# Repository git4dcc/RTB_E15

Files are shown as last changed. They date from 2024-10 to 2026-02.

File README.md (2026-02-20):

# RTB_E15




This E15 module implements a 12 channel WS2811 emulator with compatible bus timing to drive multiplex (charlieplexing) LEDs. The E15 may be cascaded with regular WS28xx chips. The number of LEDs attached is automatically detected (0-12). The LED voltage is fixed to 5V.  The intended use is to drive Multiplex Signals on Model Railway layouts via the WS28xx bus.

_Note: The E15 is nearly identical to the [RTB_E13](/../../../../git4dcc/RTB_E13), but only allows fixed LED voltage._

<details>
<summary>See also</summary>

- [RTB_E10](/../../../../git4dcc/RTB_E10)
- [RTB_E13](/../../../../git4dcc/RTB_E13)

</details>

<details>
<summary>User Guides</summary>

- [User Guide - DE](https://rtb4dcc.de/ws2811_guide_de/)
- User Guide - EN

</details>

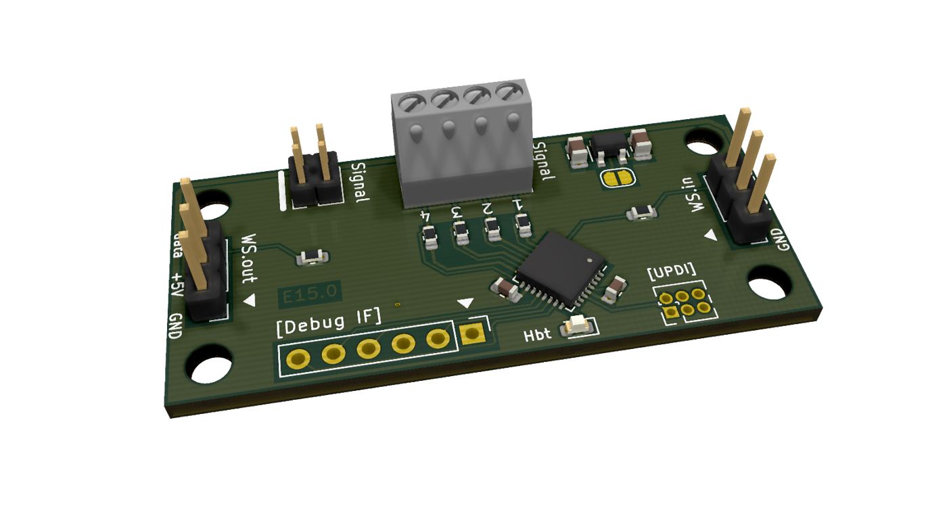
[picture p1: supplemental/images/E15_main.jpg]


The decoder has the following features,
- **Protocol**
  - WS2811 compatible timing
- **LED ports**
  - 0..12 LEDs (auto detecting)
  - Charlieplexing (Multiplexing) output
  - 256 step PWM (300Hz)
  - LED voltage fixed to 5V (see also [RTB_E13](https://github.com/git4dcc/RTB_E13))
  - gamma correction (optional)
- firmware update via V24 debug interface

# Hardware
My current PCB layout uses SMD footprints with 0.5mm pitch and 0603 parts. Reflow soldering is my recommendation, but with some experience handsoldering is also possible.

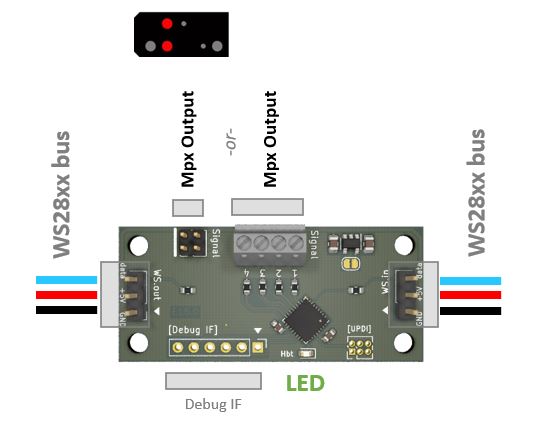
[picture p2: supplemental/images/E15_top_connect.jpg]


## PCB
- 2-layer PCB, FR4, 1.6mm
- CPU: AVR64DA32
- BUS: WS28xx
- LED: Charlieplexing

## Kicad
[Schematic](doc/E15_schematic.pdf) | [Layout](doc/E15_layout.pdf) | [BOM](doc/E15_BOM.pdf) | [Gerber](gerber)

<details>
<summary>Dependency</summary>
<br>

:yellow_circle: Requires my Kicad project library [RTB_SamacSys](/../../../../git4dcc/RTB_SamacSys) in the same directory tree.

</details>

## Firmware
Filename structure: { **pcb** }{ **code** }{ **version** }.hex

Example: **E15F0001**.hex

| | Description |
| --- | --- |
| **pcb** | Name of matching hardware (**E15**) |
| **code** | Type of code contained (**R**=rom, **B**=bootloader, **F**=flash, **U**=bld update, **P**=UPDI factory code) |
| **version** | Release version (**####**) |

## UPDI
The fuse settings as well as the P-code (E15Pxxxx.hex) has to be installed by using UPDI.<br>

<details>
<summary>Details</summary>

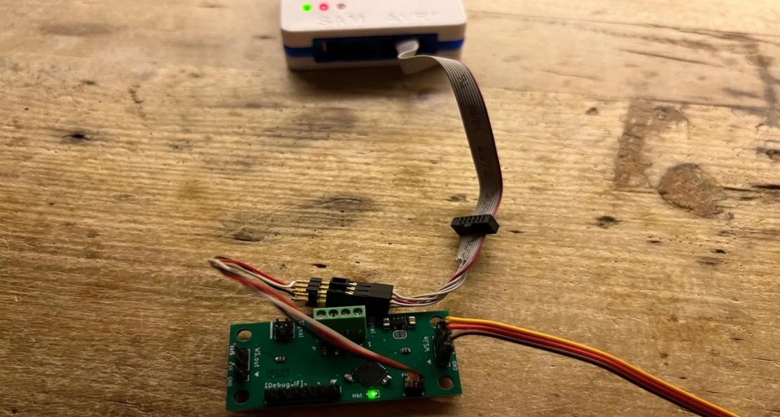
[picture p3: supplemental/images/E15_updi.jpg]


| Fuse Setting | P-code Install |
| --- | --- |
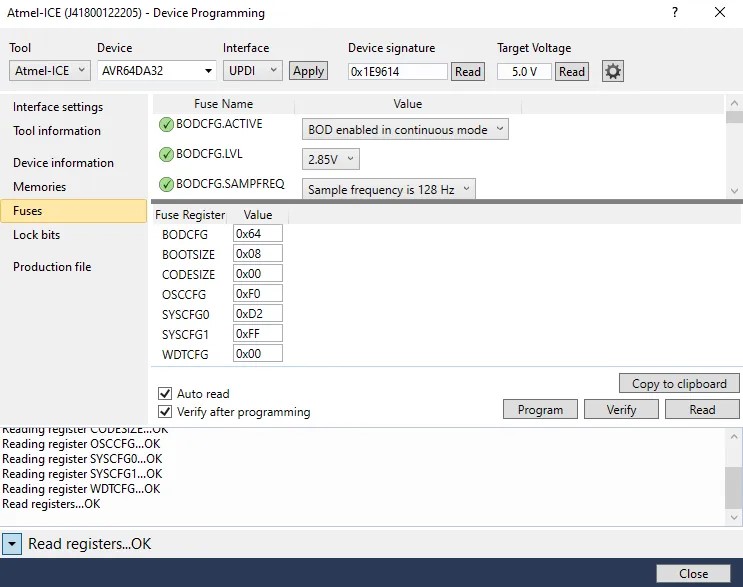
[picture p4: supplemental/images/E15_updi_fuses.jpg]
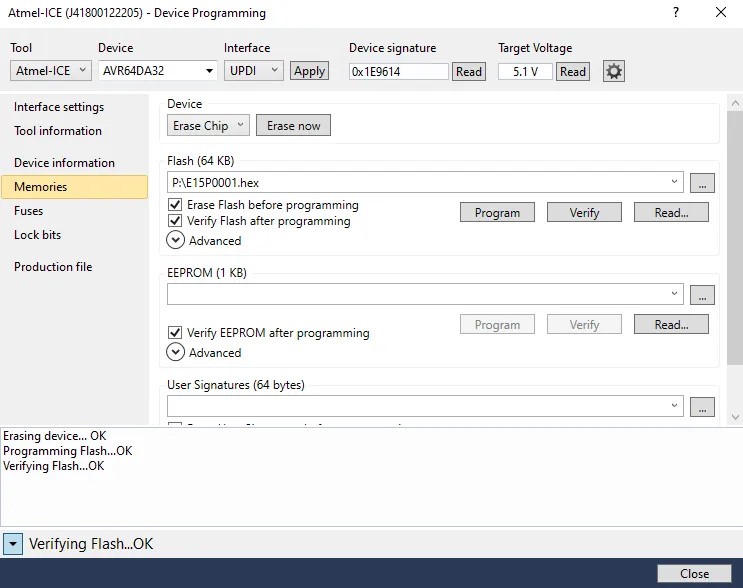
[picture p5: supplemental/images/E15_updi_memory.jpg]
|||

</details>

## Debug Interface
Subsequent code updates can be done via the built-in serial debug interface.<br>

<details>
<summary>Details</summary>

- connect the serial cable **(1Mb, 8N1, RTS/CTS)**
- press 'break' within the VT100 terminal to bump the module to console prompt
- upload the firmware file (E15Fxxxx.hex)
- for more details, refer to the 'User Guide'

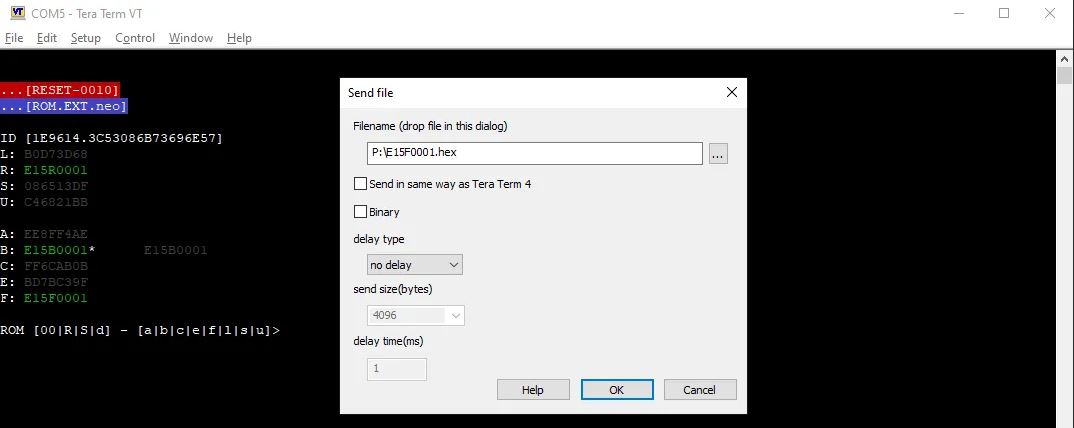
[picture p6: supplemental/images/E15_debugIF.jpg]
  

</details>

# Software
The LED intensity values for the individual LEDs need to be transmitted over the bus, with N being the number of configured LEDs.

```
Byte order:     {led_0} ... {led_N}
```

# Images
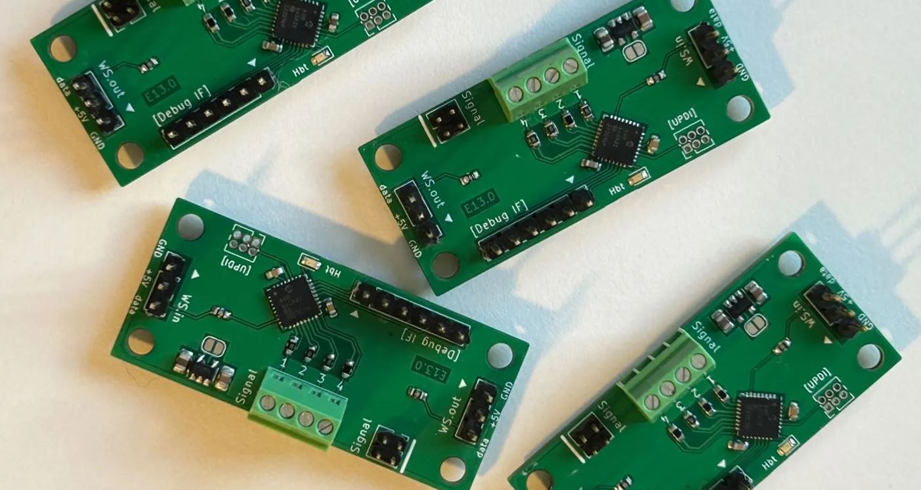
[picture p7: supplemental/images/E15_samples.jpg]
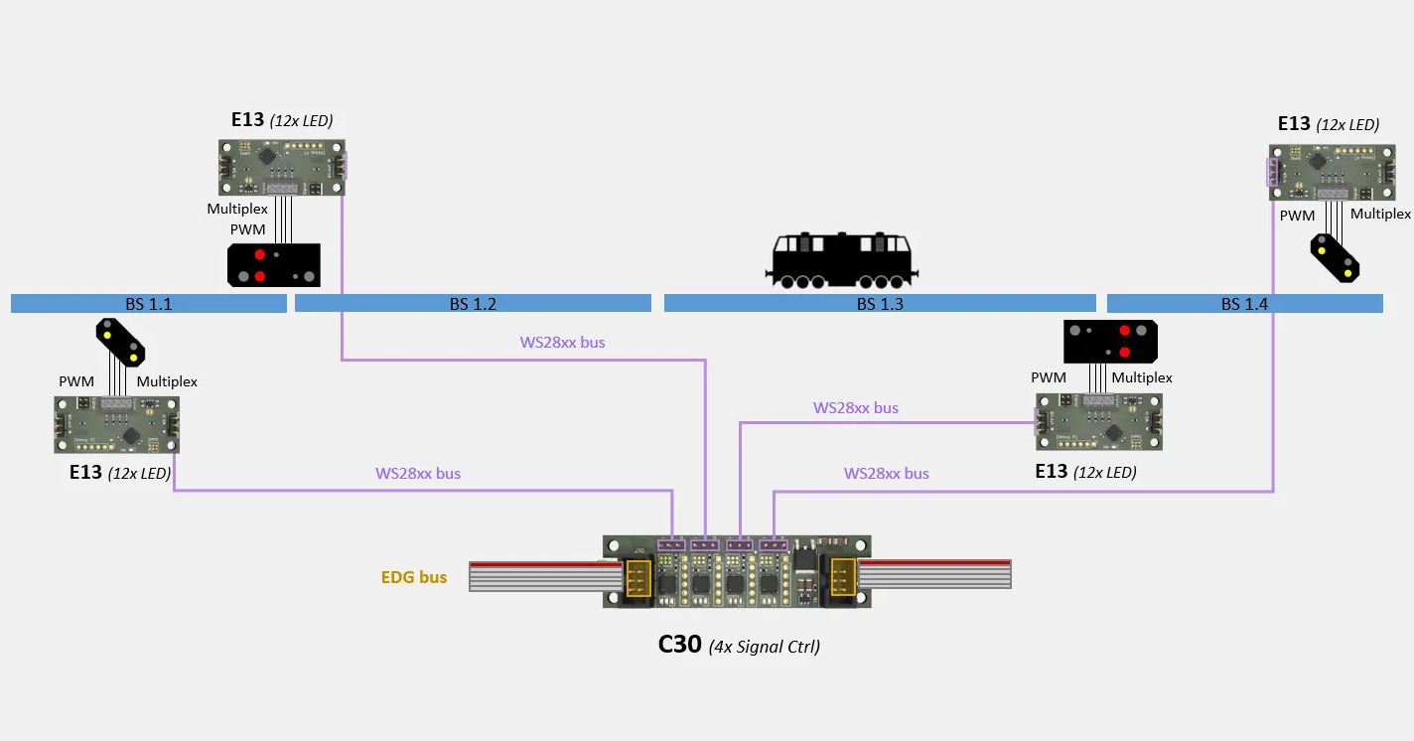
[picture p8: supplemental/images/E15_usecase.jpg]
 

This project is intended for hobby use only and is distributed in accordance with the Apache License 2.0 agreement.

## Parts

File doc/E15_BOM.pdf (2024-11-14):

Item# | Designator | Qty | Manufacturer | Mfg Part# | Description / Value | Package/Footprint | Type | Notes
1 | C2,C3 | 2 | Murata Electronics | GCM188R71C104KA37J | Multilayer Ceramic Capacitors MLCC 0.1 uF 16 VDC 10% X7R | 0603 | SMD | any compatible part will do as well
2 | D2 | 1 | ROHM Semiconductor | SMLD12EN1WT86 | Standard LEDs - SMD Grn 140mcd | 0603 | SMD | any compatible part will do as well
3 | R17,R16,R15,R14 4 | YAGEO | RC0603FR-07120RL | Thick Film Resistors 120 Ohms 100mW 1% | 0603 | SMD | any compatible part will do as well
4 | R19,R18 | 2 | YAGEO | AC0603FR-07160RL | Thick Film Resistors 160 Ohms 100mW 1% | 0603 | SMD | any compatible part will do as well
5 | R20 | 1 | YAGEO | RC0603JR-103K3L | Thick Film Resistors 3.3 kOhms 100-200mW 5% | 0603 | SMD | any compatible part will do as well
6 | C4,C1 | 2 | Murata Electronics | GRM21BZ7YA475ME15L | Multilayer Ceramic Capacitors MLCC 4.7 uF 35 VDC 20% X7R | 0805 | SMD | any compatible part will do as well
7 | U2 | 1 | Microchip Technology | MIC5205-5.0YM5-TR | LDO Voltage Regulators 5V 150mA | SOT-23-5 | SMD | any compatible part will do as well
8 | U1 | 1 | Microchip Technology | AVR64DA32-I/RXB | 8-bit Microcontrollers - MCU 64 KB 32-pin | QFN-32 5x5mm P0.5mm | SMD

Item# | Designator | Qty | Manufacturer | Mfg Part# | Description / Value | Package/Footprint | Type | Notes 1 | D2 | 1 | Vishay | SSA33L-E3/61T | Schottky Diodes & Rectifiers 3.0 Amp 30 Volt | SMA | SMD | any compatible part will do as well

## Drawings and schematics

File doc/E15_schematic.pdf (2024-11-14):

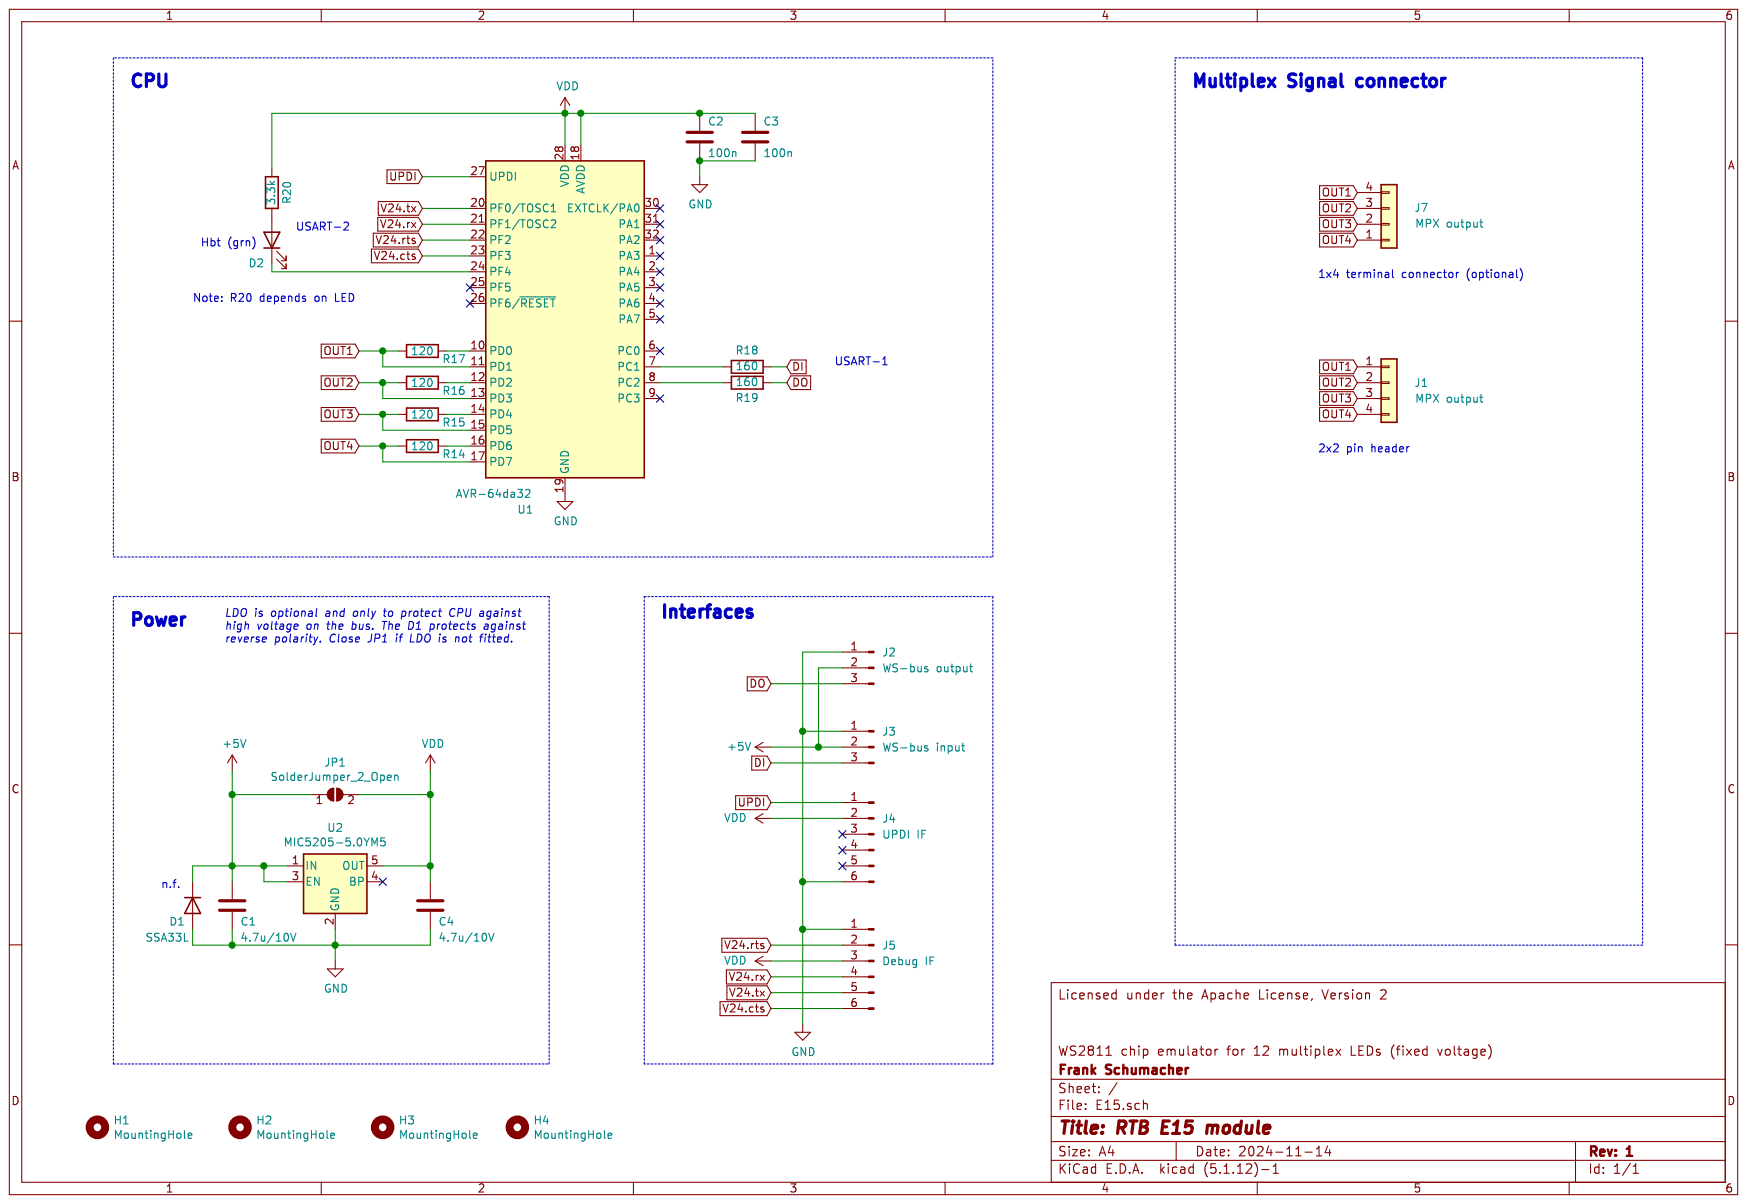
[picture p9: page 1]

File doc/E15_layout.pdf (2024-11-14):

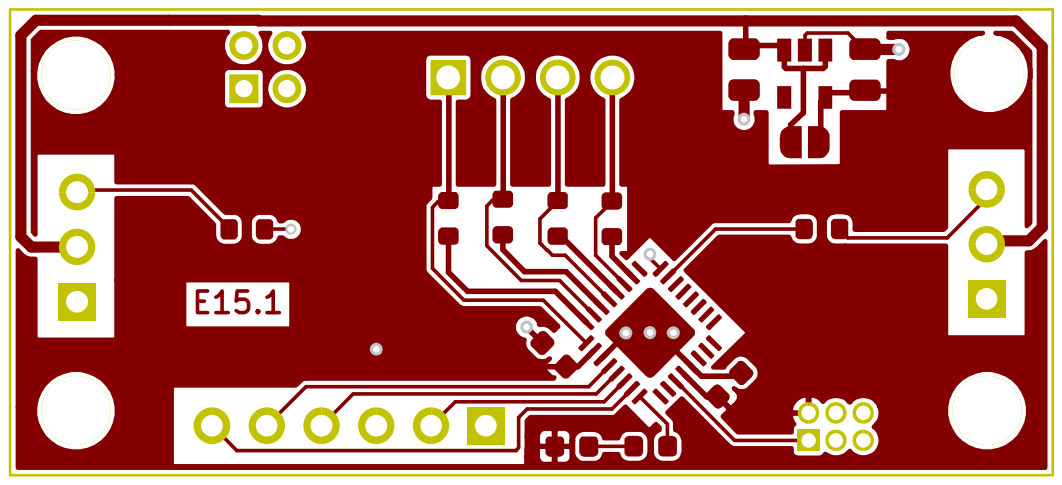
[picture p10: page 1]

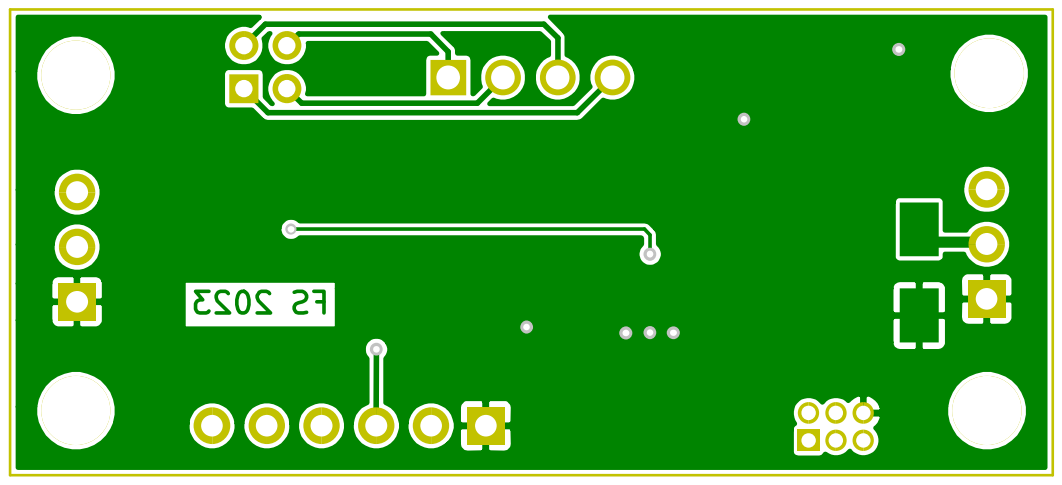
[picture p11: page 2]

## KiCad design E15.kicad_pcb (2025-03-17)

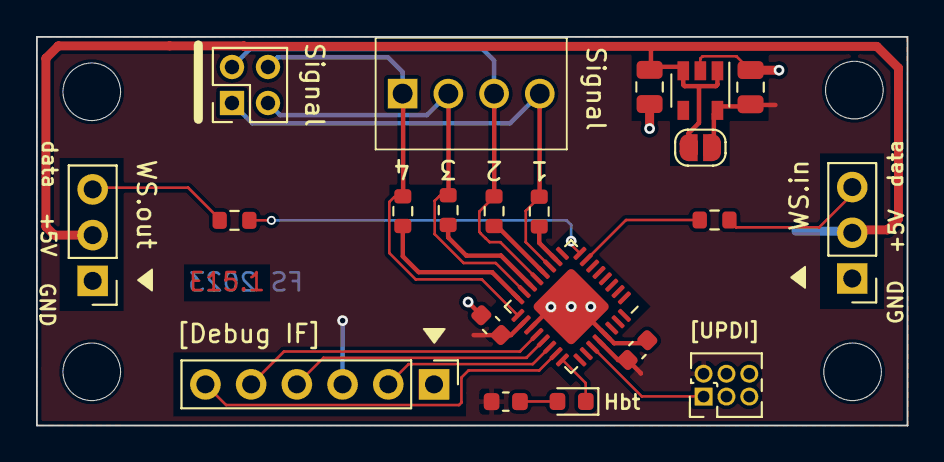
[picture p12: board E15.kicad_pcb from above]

Board: 2 copper layers, 48.4 x 21.6 mm, 26 parts (1 on the bottom side), 22 nets.

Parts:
C1, C4: 4.7u/10V; C_0805_2012Metric
C2, C3: 100n; C_0603_1608Metric
D1: SSA33L; D_SMA
D2: HBT(green); LED_0603_1608Metric
H1, H2, H3, H4: MountingHole; MountingHole_3.2mm_M3_DIN965
J1: MPX output; PinHeader_2x02_P2.00mm_Vertical
J2: WS-bus output; PinHeader_1x03_P2.54mm_Vertical
J3: WS-bus input; PinHeader_1x03_P2.54mm_Vertical
J4: UPDI IF; PinHeader_2x03_P1.27mm_Vertical
J5: Debug IF; PinHeader_1x06_P2.54mm_Vertical
J7: MPX output; 1725672
JP1: SolderJumper_2_Open; SolderJumper-2_P1.3mm_Open_RoundedPad1.0x1.5mm
R14, R15, R16, R17: 120; R_0603_1608Metric
R18, R19: 160; R_0603_1608Metric
R20: 3.3k; R_0603_1608Metric
U1: AVR-64da32; QFN-32-1EP_5x5mm_P0.5mm_EP3.1x3.1mm
U2: MIC5205-5.0YM5; SOT-23-5

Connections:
+5V: C1.1, D1.1, J2.2, J3.2, JP1.1, U2.1, U2.3
DI: J3.3, R18.2
DO: J2.3, R19.2
GND: C1.2, C2.2, C3.2, C4.2, D1.2, J2.1, J3.1, J4.6, J5.1, U1.19, U1.29, U1.33, U2.2
unnamed: D2.1, U1.24
unnamed: D2.2, R20.1
unnamed: R14.1, U1.16
unnamed: R15.1, U1.14
unnamed: R16.1, U1.12
unnamed: R17.1, U1.10
unnamed: R18.1, U1.7
unnamed: R19.1, U1.8
OUT1: J1.1, J7.4, R17.2, U1.11
OUT2: J1.2, J7.3, R16.2, U1.13
OUT3: J1.3, J7.2, R15.2, U1.15
OUT4: J1.4, J7.1, R14.2, U1.17
UPDI: J4.1, U1.27
V24.cts: J5.6, U1.23
V24.rts: J5.2, U1.22
V24.rx: J5.4, U1.21
V24.tx: J5.5, U1.20
VDD: C2.1, C3.1, C4.1, J4.2, J5.3, JP1.2, R20.2, U1.18, U1.28, U2.5

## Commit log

2024-11-14 mod: documentation
    [E15.kicad_pcb, E15.sch]
2025-03-17 add: MPX device finger print file
    [E15.kicad_pcb]

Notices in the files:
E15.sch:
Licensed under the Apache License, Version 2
